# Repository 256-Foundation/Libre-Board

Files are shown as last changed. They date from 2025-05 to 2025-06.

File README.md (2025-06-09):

# Libre-Board
Open Source Bitcoin Mining Control Board.
Learn more at https://libreboard.org/

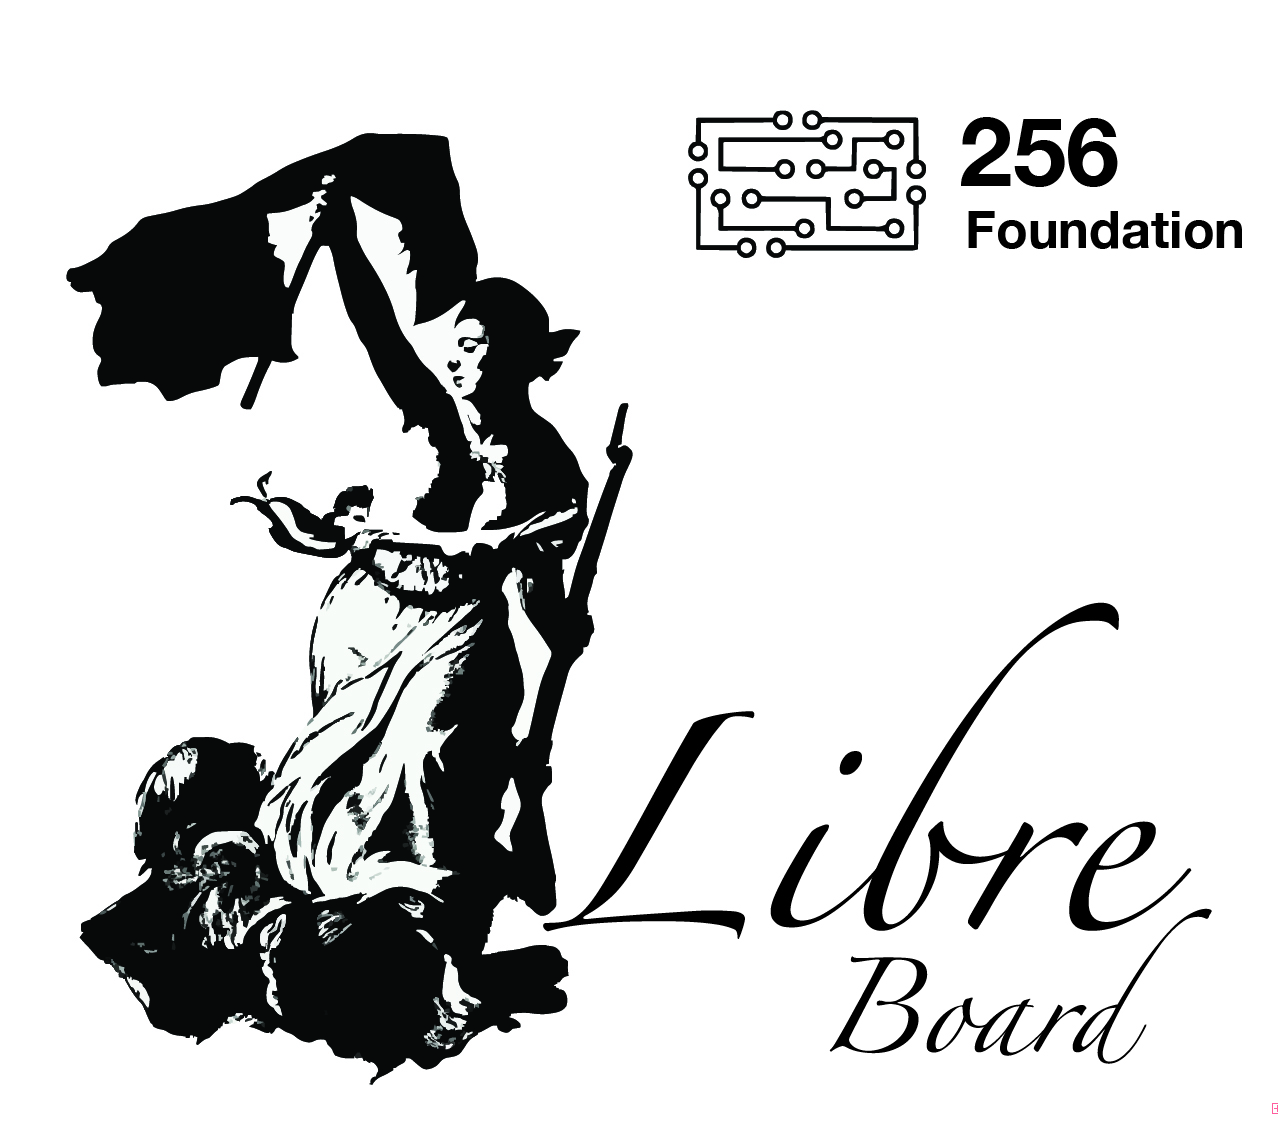
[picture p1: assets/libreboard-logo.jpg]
Libre Logo


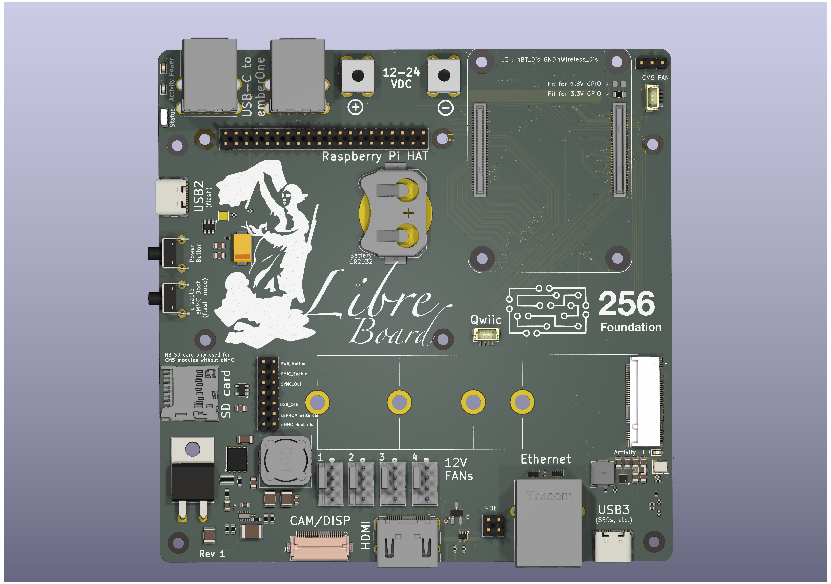
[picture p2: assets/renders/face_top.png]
Libre Board Top Face View


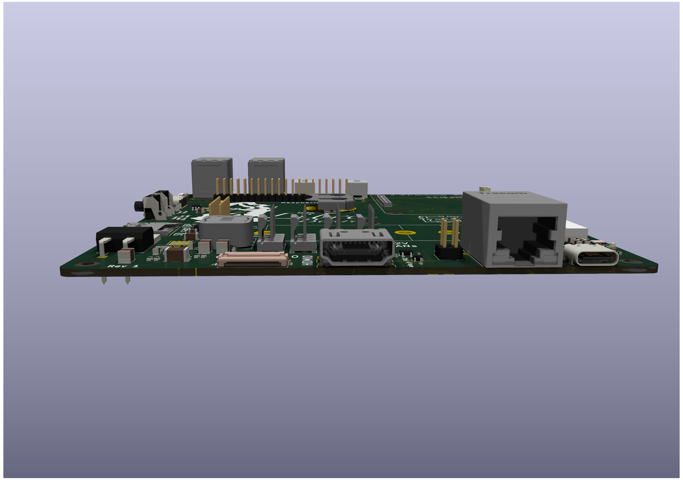
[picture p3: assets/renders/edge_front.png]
Libre Board Front Edge View


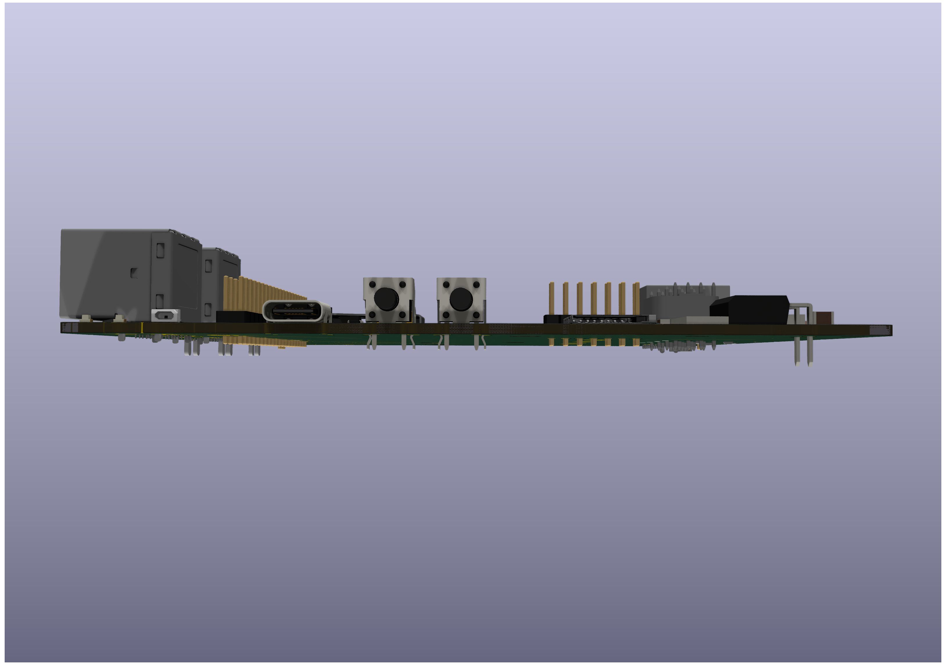
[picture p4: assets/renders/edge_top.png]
Libre Board Top Edge View


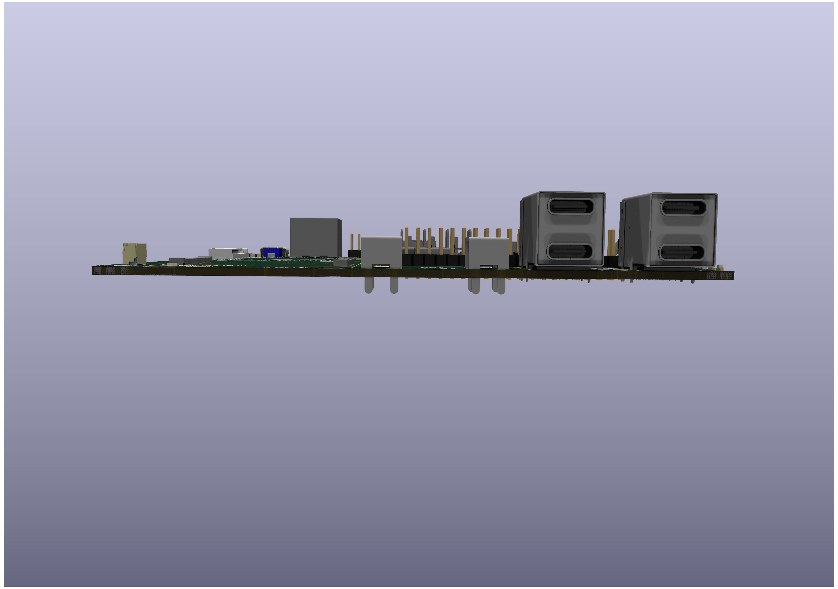
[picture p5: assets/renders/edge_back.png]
Libre Board Back Edge View


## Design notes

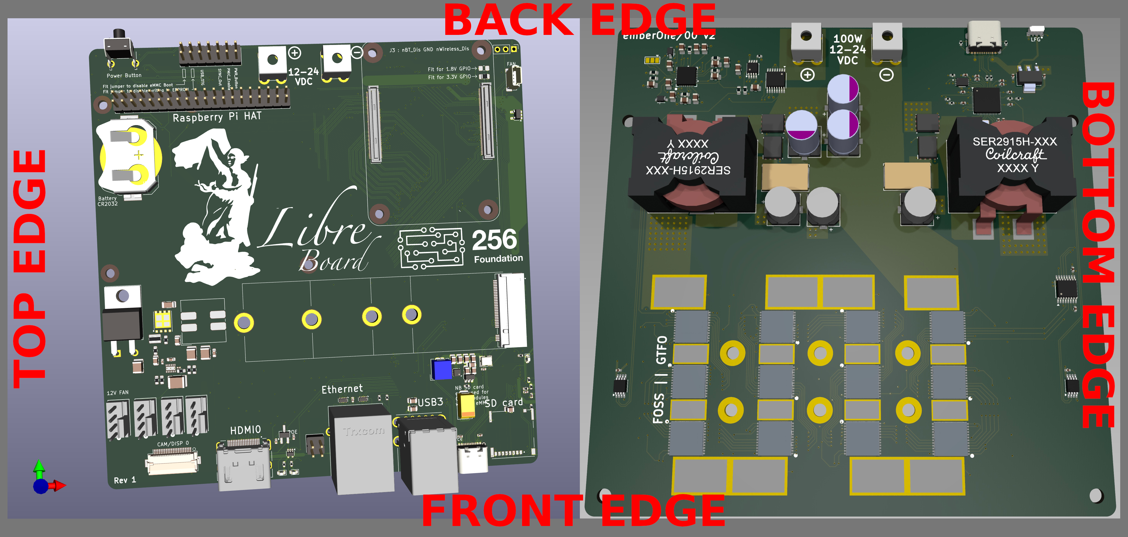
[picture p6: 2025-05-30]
assets/libreX.png

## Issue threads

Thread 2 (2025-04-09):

Change USB-A Ports to USB-C

Schnitzel, 2025-04-09:
currently Raspberry Pi Compute Module 5 IO board has two USB3.0 Ports of type A. as the EmberOne has USB-C we also want USB-C connectors

Closed 2025-06-09.

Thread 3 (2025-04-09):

Fan Connectors

Schnitzel, 2025-04-09:
Raspberry Pi Compute Module 5 IO board has a single JST-SH PWM fan connector - which we want to keep to cool any RaspberryPi
We need 4 fan connectors of the same type as regular fans but only 1 PWM signal for them

Closed 2025-09-24.

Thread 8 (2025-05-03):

Feature request: provision for graceful shutdown on power loss

rkuester, 2025-05-03:
Mujina OS would like the ability to gracefully shut down in the event of a power loss to shut down applications, write logs, avoid filesystem corruption, etc., but it needs a little help from the hardware. Perhaps supercaps or a small battery keeping the CM5 powered in the event of a power loss, and signaling for Linux to determine that the power has been lost. Having at least ten seconds of reserve would be ideal, but we might be able to make due with less.

Schnitzel, 2025-05-05:
Ah great idea! Let me look what we could leverage from existing solutions, maybe there is a Raspberry PI HAT that already provides such a solution?

zbomz, 2025-05-05:
I love this idea, but I would caution to not take it lightly thinking it's and easy implementation. We had to implement a small backup battery on the Owlet base station to ensure we could alert the user of a power loss in order to meet FDA requirements. The most challenging part of implementing something like this is designing for the worst case scenario of having multiple asynchronous, bursty loads (wifi, hdmi, ethernet, compute, etc.) fire at the same time when operating from the battery before the loads can be disabled. Judging by the 3D renderings I've seen on X, it looks like a CR2032 primary coin cell is being used to supply the backup power (sorry for the ensuing rant if I'm wrong on this).

While the capacity of the cell might be high enough to last for the requested 10 seconds, its internal impedance will be an issue. Primary coin cells have relatively high internal impedance that will cause the battery voltage to droop prohibitively low during short load bursts and result in a brown out. For example, the typical max "pulse current" for a lithium manganese CR2032 cell is 15mA. The idle power consumption of the CM5 is typically 400mA. The operating power consumption is typically 900mA. Add the possibility of Wifi transmitting when power is lost, and you're looking at over 1 amp of current draw. No single coin cell is going to be able to support that. You need something with low internal impedance. A small lithium polymer rechargeable battery with an accompanying charge controller IC is your best low-cost option for meeting the pulse current requirements, but it may not be suitable due to its sensitivity to temperatures above 70C.

zbomz, 2025-05-05:
Got it. Sorry for the rant about the coin cell! lol

Out of curiosity, I started musing about what it would take to supply 1A at 5V for 10 seconds. I'm trying to think of the lowest cost way to do it. What kind of budget are you hoping to implement this for?

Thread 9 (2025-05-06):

Feature request: S9 board plug and play

TimothyShimmin, 2025-05-06:
Hey I just heard about this [project](https://x.com/Schnitzel/status/1919446976577540429), that one of the goals is modularity.

Is there any intention of supporting boards straight out of corpo miners? I don't know what the limitations would be for that but it'd be nice to rip one out of an otherwise busted miner and slot it into this board.

econoalchemist, 2025-05-28:
There's a few different approaches: One would be to flash [Mujina](https://mujina.org/) onto an existing S9 board, though this probably won't be viable until sometime after the first release. Two would be to use Libre Board as the controller running Mujina and then connect it to the S9 hashboards with the [Adit Board](https://github.com/skot/aditBoard) adapter. A third option would be to fork Libre Board and modify it to be a direct replacement.

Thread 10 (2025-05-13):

Feature request: at least 4 USB-C ports directly on Libre Board

rkuester, 2025-05-13:
The Libre Board should have at least four USB-C ports in addition to the power and diagnostic port currently adjacent to the SD card slot.

The design currently has only two, but I think that's insufficient. Two ports allows for only one hash board plus one accessory (USB drive, keyboard, etc.); however, one of our modular system's selling points is that you can connect multiple hash boards via USB. One of the firmware's selling points is that it can talk to a variable number and types of hash boards, connected via USB. Thus I believe the out-of-the-box hardware should be able to show off these features without resort to an external hub.

Having four ports allows for three hash boards plus one accessory. Additionally, the design of ICs and connectors is such that four ports is like as easy to design-in as three ports.

If board space is an issue, I'd consider shifting the MIPI, HDMI, and Ethernet connectors over and eliminating the space between the Ethernet and HDMI connector.

Schnitzel, 2025-06-09:
this has been implemented in the newest version - see 2 USB3 stacks on the top:

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

this is not routed yet, also there is no USB controller yet, leaving this open until we have that.

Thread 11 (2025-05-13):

Feature request: board holes which align with those on emberOne

rkuester, 2025-05-13:
If Libre Board had holes in the corners which lined up with the holes on emberOne's corners, they could be stacked together nicely with standoffs.

Schnitzel, 2025-05-30:
yep, that's already part of the plan

Schnitzel, 2025-06-09:
this has been implemented in the newest version:

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

Schnitzel, 2025-06-09:
actually I just realized that the holes should probably align to the top of the image and not to the bottom as they do right now, need to move quite some stuff around for this

Closed 2025-06-09.

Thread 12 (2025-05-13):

Feature request: route serial console pins to thru-holes for .100 header

rkuester, 2025-05-13:
Pins 6, 8, and 10 on the Raspberry Pi 40-pin header are often used for a Linux serial console—The Way to get a command shell without needing monitors, keyboards, a configured network, etc., and often used for development and debugging when nothing else is working. It would ideal to preserve semi-easy access to the serial console even when a hat is in use on the 40-pin header.

Could we please route those signals to thru-holes for a 3-pin, .100"-centers header, even if we don't populate it with a header or connector? Ideally it'd be on a board edge so that a right-angle connector is an option.

As a helpful byproduct, the obvious use of those signals on the PCB might deter hat developers from using those pins for other purposes. We might mention that in our documentation.

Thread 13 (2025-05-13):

Feature request: an indicator LED identical to that of the emberOne

rkuester, 2025-05-13:
The emberOne has an RGB LED module we'll use in software for indicating presence, faults, etc. It's on the same board edge as the power rails. It would be nice if Libre Board had the same indicator, and if it were visible in parallel if the boards were all connected via a power rails.

rkuester, 2025-06-05:
I'd use the same [SK6812](https://www.adafruit.com/product/4691) @skot is using on the emberOne. It'll be slick if the hash boards and Libre board match.

The SK6812 uses an unlocked, one-pin data interface. It definitely requires connection to a SPI-capable data line on a Linux-based machine, to meet the timing requirements. Bit-banging from bare metal or a RTOS on a microcontroller might work to meet the SK6812's timing requirements, but Linux can't counted on to bit-bang that precisely.

It'll leave it to you to decide which SPI-capable pin this should be. Taking a quick glance at the CM5, it seems there are possibilities both on the HAT-compatible 40-pin header and exclusively on the 100-pin connectors. Putting it on the 40-pin's signals probably makes it more compatible with alternate compute modules. The LED does not need the SPI clock nor MISO. To not consume that SPI bus completely, I'd gate the signal to the LED with a chip select (driven low when off).

I considered the similar but easier-to-bit-bang [SK9822](https://learn.adafruit.com/adafruit-dotstar-leds/overview), which has a clock and data signal, but I didn't see any right-angle versions of those.

rkuester, 2025-06-05:
For completeness, I'll mention that we could likely implement something fancy using the PIO on the RPi CM5 to delegate timing requirements to hardware without using SPI per se. However, this approach is quite specific to the CM5 and might cut off our compatibility with other compute modules.

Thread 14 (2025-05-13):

Feature request: an 4-pin connector compatible with the Adafruit STEMMA and Sparkfun Qwicc standard

rkuester, 2025-05-13:
It might be a nice touch if we put a 4-pin JST SH connector on the board for the expansion I2C bus, compatible with the [Adafruit STEMMA](https://learn.adafruit.com/introducing-adafruit-stemma-qt/technical-specs) and [Sparkfun Qwicc](https://www.sparkfun.com/qwiic) standard. This would open plug-and-play access to the many sensor, actuator, indicator, etc. modules hobbyists use via those standards.

I realize this could be done with a hat; however, we could do this with just a connector, or the footprint for a connector, and instantly have a lot of fun out-of-the-box.

Closed 2025-06-09.

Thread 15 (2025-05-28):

Feature request: a momentary pushbutton for eMMC boot mode selection

rkuester, 2025-05-28:
I propose adding a momentary pushbutton in parallel with the existing boot jumper header that temporarily grounds the boot select pin when pressed during power-on. This would remove the hassle of finding and positioning jumpers, significantly improving the Mujina Firmware flashing process for developers and end users.

Currently, enabling USB bootloader mode on the CM5 daughterboard requires manually placing a jumper across the boot header pins, which is cumbersome during frequent development cycles. Since all CM5-compatible compute modules with eMMC don't boot from SD card, using the boot select jumper to enter USB loader mode is critical for programming these modules with rpiboot. I've tested this behavior using a jumper as a momentary connection and confirmed the CM5 only needs the boot pin pulled low for a few seconds after power is applied—once the boot sequence completes, the CM5 enters loader mode and waits for programming via USB.

Schnitzel, 2025-06-09:
this has been implemented in the newest version - see the secondary button on the left/top edge

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

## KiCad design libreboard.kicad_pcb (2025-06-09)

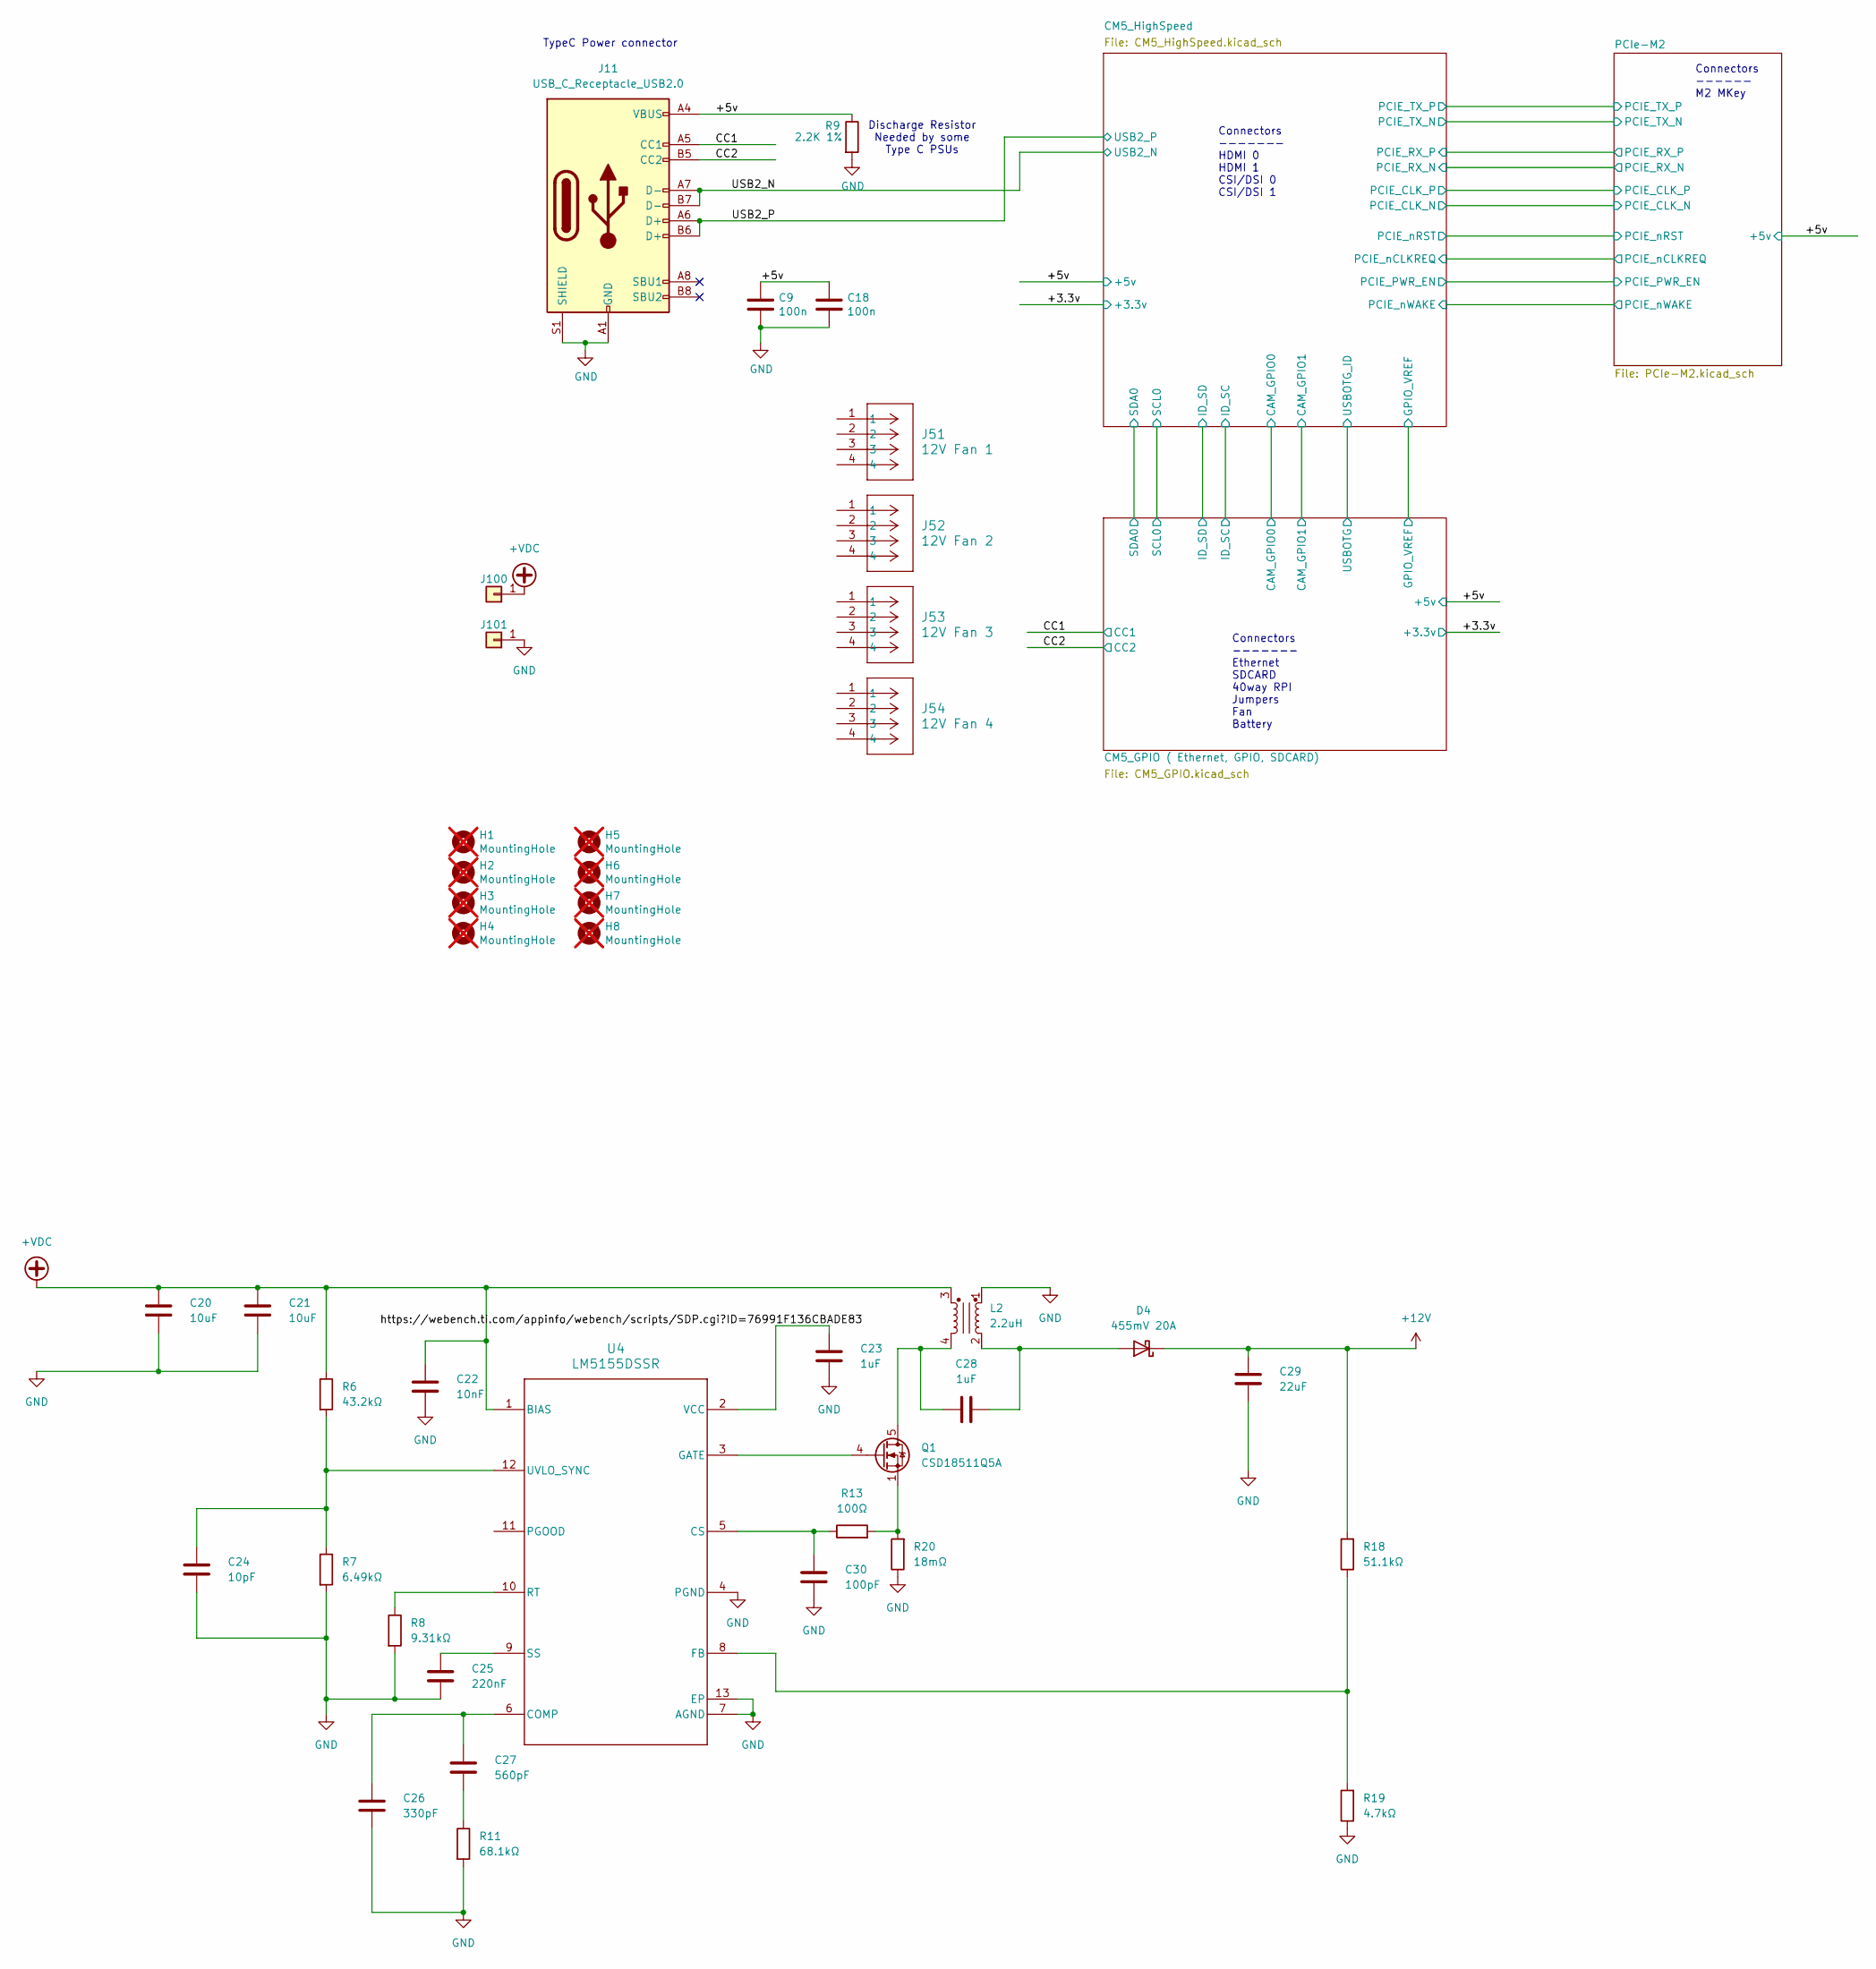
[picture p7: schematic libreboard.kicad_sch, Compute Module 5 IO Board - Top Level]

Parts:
C9, C18: 100n; C_0402_1005Metric; Part Description 0.1uF 10% 16V Ceramic Capacitor X7R 040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
C20, C21: 10uF; C_1210_3225Metric
C22: 10nF; C_0603_1608Metric
C23: 1uF; C_0603_1608Metric
C24: 10pF; C_0201_0603Metric
C25: 220nF; C_1812_4532Metric
C26: 330pF; C_0402_1005Metric
C27: 560pF; C_0805_2012Metric
C28: 1uF; C_1206_3216Metric
C29: 22uF; C_1210_3225Metric
C30: 100pF; C_0805_2012Metric
D4: 455mV 20A; TO-220-2_Horizontal_TabDown
H1, H2, H3, H4, H5, H6, H7, H8: MountingHole; MountingHole_2.7mm_M2.5_DIN965; Part Description M2.5 mounting hole; not fitted
J11: USB_C_Receptacle_USB2.0; USB_C_Receptacle_GCT_USB4105-xx-A_16P_TopMnt_Horizontal; Part Description USBC USB2 data and power connector
J51: 12V Fan 1; CONN_SD-47053-001_H10p00_MOL
J52: 12V Fan 2; CONN_SD-47053-001_H10p00_MOL
J53: 12V Fan 3; CONN_SD-47053-001_H10p00_MOL
J54: 12V Fan 4; CONN_SD-47053-001_H10p00_MOL
J100, J101: Screw Terminal; 7770-screw-terminal; PARTNO 36-7770
L2: 2.2uH; L_Bourns_SRF1260
Q1: CSD18511Q5A; VSONP-8-1EP_5x6_P1.27mm; PARTNO CSD18511Q5A
R6: 43.2kΩ; R_0603_1608Metric
R7: 6.49kΩ; R_0603_1608Metric
R8: 9.31kΩ; R_0603_1608Metric
R9: 2.2K 1%; R_0402_1005Metric; Part Description Resistor 2.2K M1005 1% 63mW
R11: 68.1kΩ; R_0603_1608Metric
R13: 100Ω; R_0603_1608Metric
R18: 51.1kΩ; R_0603_1608Metric
R19: 4.7kΩ; R_0603_1608Metric
R20: 18mΩ; R_0612_1632Metric
U4: LM5155DSSR; DSS0012B

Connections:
+12V: C29.2, D4.1 (K), R18.2
+VDC: C20.2, C21.2, C22.2, J100.1, L2.3, R6.1, U4.1 (BIAS)
/+5v: C9.1, C18.1, J11.A4 (VBUS), J11.A9 (VBUS), J11.B4 (VBUS), J11.B9 (VBUS), R9.1; also elsewhere on the board
/CC1: J11.A5 (CC1); also elsewhere on the board
/CC2: J11.B5 (CC2); also elsewhere on the board
/USB2_N: J11.A7 (D-), J11.B7 (D-); also elsewhere on the board
/USB2_P: J11.A6 (D+), J11.B6 (D+); also elsewhere on the board
GND: C9.2, C18.2, C20.1, C21.1, C22.1, C23.1, C24.1, C25.1, C26.1, C29.1, C30.1, J11.A1 (GND), J11.A12 (GND), J11.B1 (GND), J11.B12 (GND), J11.S1 (SHIELD), J101.1, L2.1, R7.2, R8.2, R9.2, R11.2, R19.1, R20.1, U4.4 (PGND), U4.7 (AGND), U4.13 (EP); also elsewhere on the board
unnamed: C27.1, R11.1
unnamed: C28.1, L2.4, Q1.5 (D), Q1.6 (D), Q1.7 (D), Q1.8 (D)
unnamed: C28.2, D4.2 (A), L2.2
unnamed: Q1.4 (G), U4.3 (GATE)
unnamed: Q1.1 (S), Q1.2 (S), Q1.3 (S), R13.2, R20.2
unnamed: C26.2, C27.2, U4.6 (COMP)
unnamed: C30.2, R13.1, U4.5 (CS)
unnamed: R18.1, R19.2, U4.8 (FB)
unnamed: R8.1, U4.10 (RT)
unnamed: C25.2, U4.9 (SS)
unnamed: C24.2, R6.2, R7.1, U4.12 (UVLO_SYNC)
unnamed: C23.2, U4.2 (VCC)

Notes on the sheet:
Connectors ------- Ethernet SDCARD 40way RPI Jumpers Fan Battery
Connectors ------ M2 MKey
Discharge Resistor Needed by some Type C PSUs
TypeC Power connector
Connectors ------- HDMI 0 HDMI 1 CSI/DSI 0 CSI/DSI 1

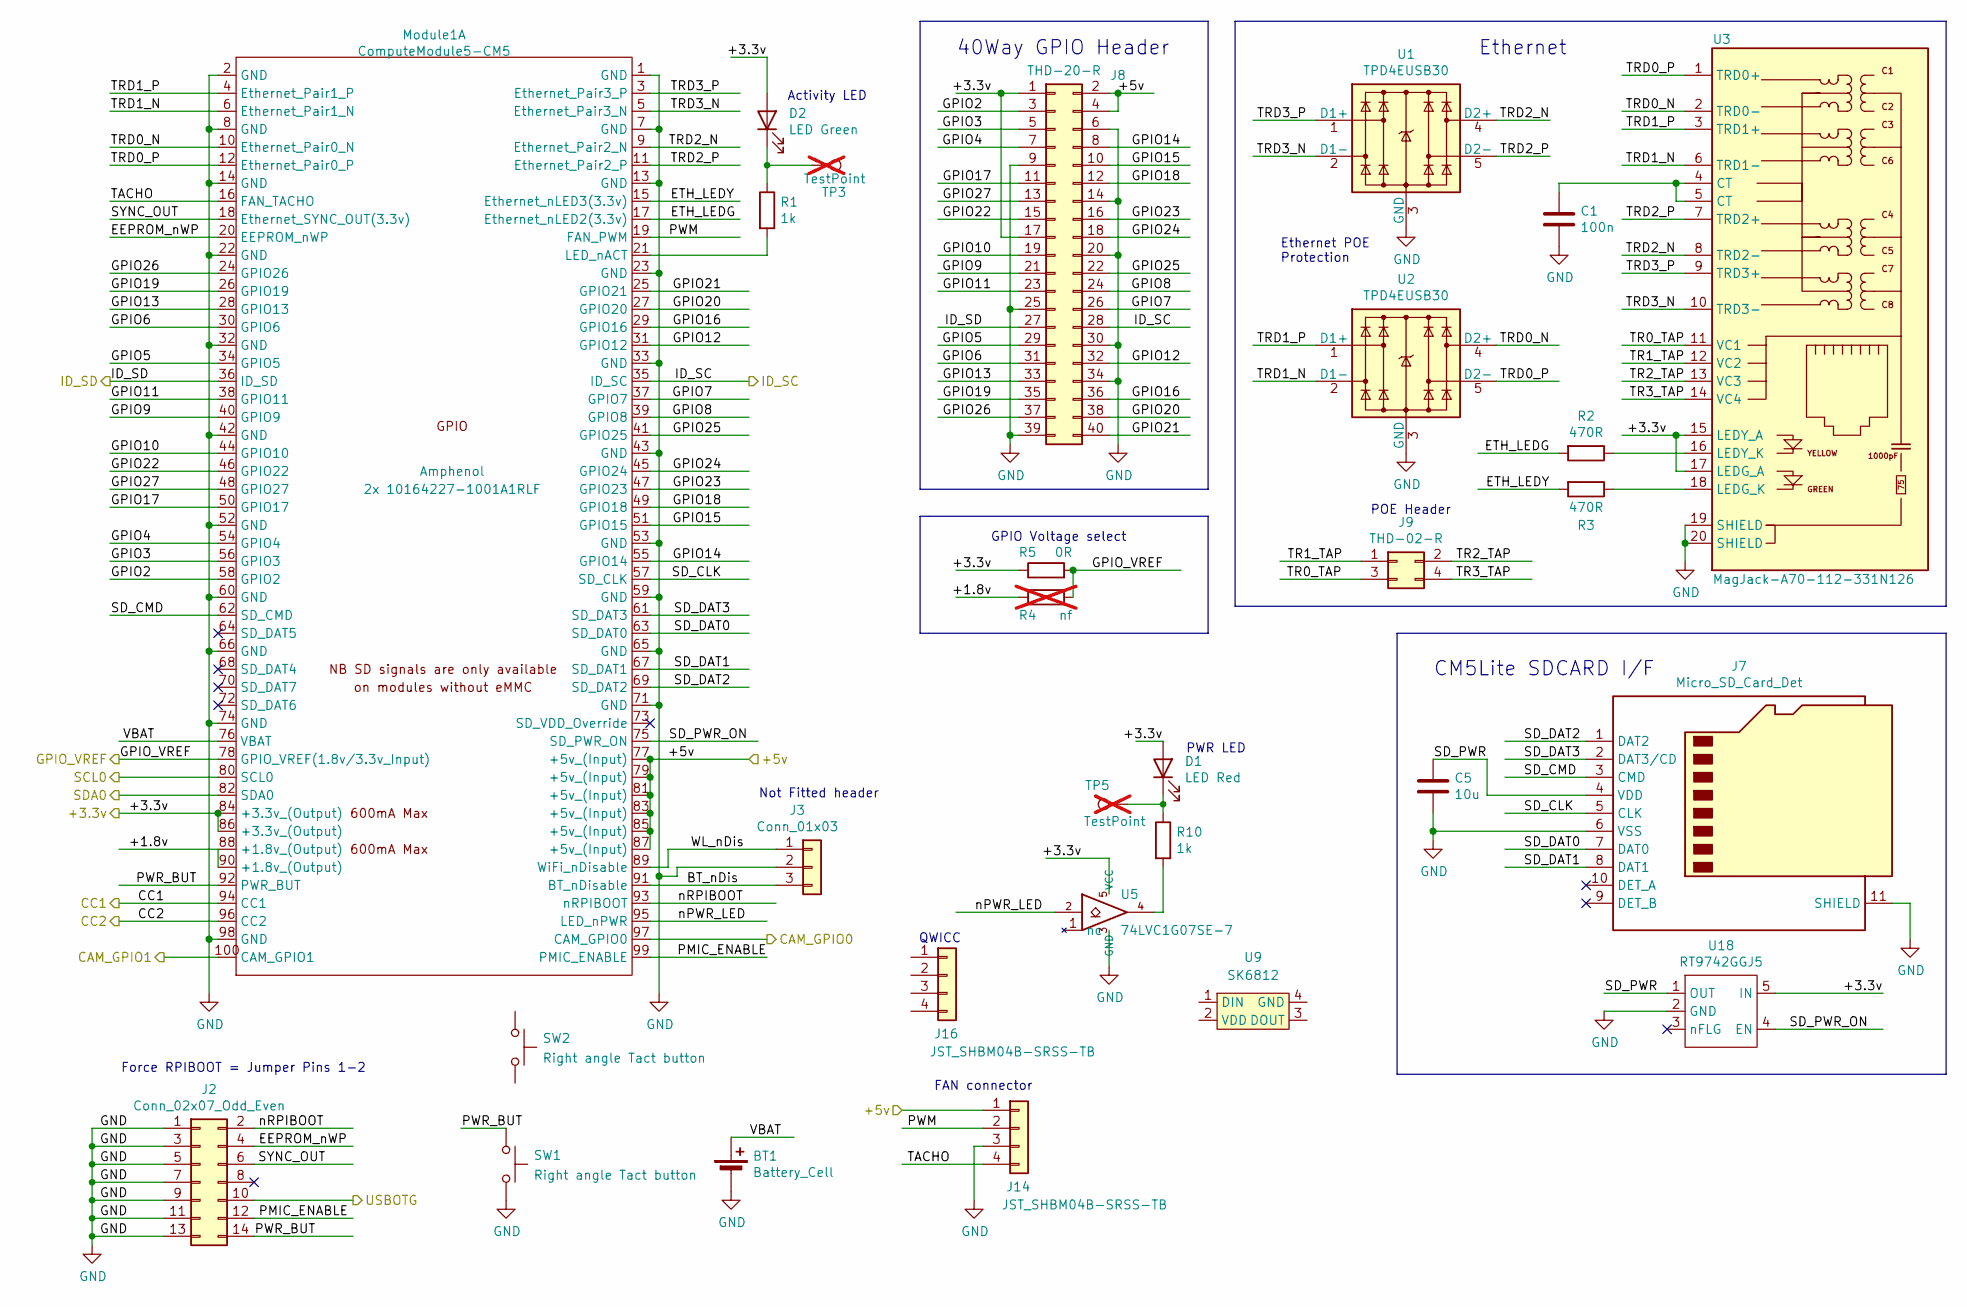
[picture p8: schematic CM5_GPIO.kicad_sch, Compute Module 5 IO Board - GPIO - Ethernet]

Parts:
BT1: Battery_Cell; BatteryHolder_Keystone_3034_1x20mm; Part Description Battery Retainer Coin, 20.0mm 1 Cell SM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
C1: 100n; C_0402_1005Metric; Part Description 0.1uF 10% 16V Ceramic Capacitor X7R 040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
C5: 10u; C_0805_2012Metric; Part Description 10uF 10% 10V Ceramic Capacitor X7R 0805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
D1: LED Red; LED_0603_1608Metric; Part Description Red 620nm LED Indication - Discrete 2.2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
D2: LED Green; LED_0603_1608Metric; Part Description Green 572nm LED Indication - Discrete 2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
J2: Conn_02x07_Odd_Even; PinHeader_2x07_P2.54mm_Vertical; Part Description PinHeader_2x07_P2.54mm_Vertical
J3: Conn_01x03; PinHeader_1x03_P2.54mm_Vertical; Part Description 3pin 0.1" connector
J7: Micro_SD_Card_Det; SDCARD_MOLEX_503398-1892; Part Description 9 (8 + 1) Position Card Connector micro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
J8: THD-20-R; PinHeader_2x20_P2.54mm_Vertical; Part Description PinHeader_2x20_P2.54mm_Vertical
J9: THD-02-R; PinHeader_2x02_P2.54mm_Vertical; Part Description PinHeader_2x02_P2.54mm_Vertical
J14, J16: JST_SHBM04B-SRSS-TB; JST_SH_BM04B-SRSS-TB_1x04-1MP_P1.00mm_Vertical; Part Description 4 pin vertical 1mm pitch connector
Module1: ComputeModule5-CM5; Raspberry-Pi-5-Compute-Module; Part Description 100 Position Connector Receptacle, Cent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
R1, R10: 1k; R_0402_1005Metric; Part Description Resistor 1K M1005 1% 63mW
R2, R3: 470R; R_0402_1005Metric; Part Description Resistor 470R M1005 1% 63mW
R4: nf; R_0805_2012Metric_Pad1.20x1.40mm_HandSolder; not fitted
R5: 0R; R_0805_2012Metric_Pad1.20x1.40mm_HandSolder; Part Description Resistor 0R M2012 5%
SW1, SW2: Right angle Tact button; SW_Tactile_SPST_Angled_PTS645Vx58-2LFS; Part Description Right angle through hole Tact switch
TP3, TP5: TestPoint; TestPoint_Pad_2.0x2.0mm; Part Description Test point; not fitted
U1, U2: TPD4EUSB30; USON-10_2.5x1.0mm_P0.5mm; Part Description Quad TVS diode for high speed signals (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
U3: MagJack-A70-112-331N126; TRJG0926HENL; Part Description Gigabit Ethernet Magjack
U5: 74LVC1G07SE-7; SOT-353_SC-70-5; Part Description Buffer, Non-Inverting 1 Element 1 Bit p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
U9: SK6812; LED-SMD_4P-L4.0-W1.6-L; LCSC C2890037
U18: RT9742GGJ5; SOT-23-5; Part Description Power Switch/Driver 1:1 N-Channel 1A TS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

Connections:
/+3.3v: D1.2 (A), D2.2 (A), J8.1, J8.17, Module1.84 (+3.3v_(Output)), Module1.86 (+3.3v_(Output)), R5.1, U3.15 (LEDY_A), U3.17 (LEDG_A), U5.5 (VCC), U18.5 (IN); also elsewhere on the board
/+5v: J8.2, J8.4, J14.1, Module1.77 (+5v_(Input)), Module1.79 (+5v_(Input)), Module1.81 (+5v_(Input)), Module1.83 (+5v_(Input)), Module1.85 (+5v_(Input)), Module1.87 (+5v_(Input)); also elsewhere on the board
/CC1: Module1.94 (CC1); also elsewhere on the board
/CC2: Module1.96 (CC2); also elsewhere on the board
/CM5_GPIO ( Ethernet, GPIO, SDCARD)/+1.8v: Module1.88 (+1.8v_(Output)), Module1.90 (+1.8v_(Output)), R4.1
/CM5_GPIO ( Ethernet, GPIO, SDCARD)/BT_nDis: J3.3, Module1.91 (BT_nDisable)
/CM5_GPIO ( Ethernet, GPIO, SDCARD)/CAM_GPIO0: Module1.97 (CAM_GPIO0); also elsewhere on the board
/CM5_GPIO ( Ethernet, GPIO, SDCARD)/CAM_GPIO1: Module1.100 (CAM_GPIO1); also elsewhere on the board
/CM5_GPIO ( Ethernet, GPIO, SDCARD)/EEPROM_nWP: J2.4, Module1.20 (EEPROM_nWP)
/CM5_GPIO ( Ethernet, GPIO, SDCARD)/ETH_LEDG: Module1.17 (Ethernet_nLED2(3.3v)), R2.2
/CM5_GPIO ( Ethernet, GPIO, SDCARD)/ETH_LEDY: Module1.15 (Ethernet_nLED3(3.3v)), R3.2
/CM5_GPIO ( Ethernet, GPIO, SDCARD)/GPIO2: J8.3, Module1.58 (GPIO2)
/CM5_GPIO ( Ethernet, GPIO, SDCARD)/GPIO3: J8.5, Module1.56 (GPIO3)
/CM5_GPIO ( Ethernet, GPIO, SDCARD)/GPIO4: J8.7, Module1.54 (GPIO4)
/CM5_GPIO ( Ethernet, GPIO, SDCARD)/GPIO5: J8.29, Module1.34 (GPIO5)
/CM5_GPIO ( Ethernet, GPIO, SDCARD)/GPIO6: J8.31, Module1.30 (GPIO6)
/CM5_GPIO ( Ethernet, GPIO, SDCARD)/GPIO7: J8.26, Module1.37 (GPIO7)
/CM5_GPIO ( Ethernet, GPIO, SDCARD)/GPIO8: J8.24, Module1.39 (GPIO8)
/CM5_GPIO ( Ethernet, GPIO, SDCARD)/GPIO9: J8.21, Module1.40 (GPIO9)
/CM5_GPIO ( Ethernet, GPIO, SDCARD)/GPIO10: J8.19, Module1.44 (GPIO10)
/CM5_GPIO ( Ethernet, GPIO, SDCARD)/GPIO11: J8.23, Module1.38 (GPIO11)
/CM5_GPIO ( Ethernet, GPIO, SDCARD)/GPIO12: J8.32, Module1.31 (GPIO12)
/CM5_GPIO ( Ethernet, GPIO, SDCARD)/GPIO13: J8.33, Module1.28 (GPIO13)
/CM5_GPIO ( Ethernet, GPIO, SDCARD)/GPIO14: J8.8, Module1.55 (GPIO14)
/CM5_GPIO ( Ethernet, GPIO, SDCARD)/GPIO15: J8.10, Module1.51 (GPIO15)
/CM5_GPIO ( Ethernet, GPIO, SDCARD)/GPIO16: J8.36, Module1.29 (GPIO16)
/CM5_GPIO ( Ethernet, GPIO, SDCARD)/GPIO17: J8.11, Module1.50 (GPIO17)
/CM5_GPIO ( Ethernet, GPIO, SDCARD)/GPIO18: J8.12, Module1.49 (GPIO18)
/CM5_GPIO ( Ethernet, GPIO, SDCARD)/GPIO19: J8.35, Module1.26 (GPIO19)
/CM5_GPIO ( Ethernet, GPIO, SDCARD)/GPIO20: J8.38, Module1.27 (GPIO20)
/CM5_GPIO ( Ethernet, GPIO, SDCARD)/GPIO21: J8.40, Module1.25 (GPIO21)
/CM5_GPIO ( Ethernet, GPIO, SDCARD)/GPIO22: J8.15, Module1.46 (GPIO22)
/CM5_GPIO ( Ethernet, GPIO, SDCARD)/GPIO23: J8.16, Module1.47 (GPIO23)
/CM5_GPIO ( Ethernet, GPIO, SDCARD)/GPIO24: J8.18, Module1.45 (GPIO24)
/CM5_GPIO ( Ethernet, GPIO, SDCARD)/GPIO25: J8.22, Module1.41 (GPIO25)
/CM5_GPIO ( Ethernet, GPIO, SDCARD)/GPIO26: J8.37, Module1.24 (GPIO26)
/CM5_GPIO ( Ethernet, GPIO, SDCARD)/GPIO27: J8.13, Module1.48 (GPIO27)
/CM5_GPIO ( Ethernet, GPIO, SDCARD)/GPIO_VREF: Module1.78 (GPIO_VREF(1.8v/3.3v_Input)), R4.2, R5.2
/CM5_GPIO ( Ethernet, GPIO, SDCARD)/ID_SC: J8.28, Module1.35 (ID_SC)
/CM5_GPIO ( Ethernet, GPIO, SDCARD)/ID_SD: J8.27, Module1.36 (ID_SD)
/CM5_GPIO ( Ethernet, GPIO, SDCARD)/PMIC_ENABLE: J2.12, Module1.99 (PMIC_ENABLE)
/CM5_GPIO ( Ethernet, GPIO, SDCARD)/PWM: J14.2, Module1.19 (FAN_PWM)
/CM5_GPIO ( Ethernet, GPIO, SDCARD)/PWR_BUT: J2.14, Module1.92 (PWR_BUT), SW1.1
/CM5_GPIO ( Ethernet, GPIO, SDCARD)/SD_CLK: J7.5 (CLK), Module1.57 (SD_CLK)
/CM5_GPIO ( Ethernet, GPIO, SDCARD)/SD_CMD: J7.3 (CMD), Module1.62 (SD_CMD)
/CM5_GPIO ( Ethernet, GPIO, SDCARD)/SD_DAT0: J7.7 (DAT0), Module1.63 (SD_DAT0)
/CM5_GPIO ( Ethernet, GPIO, SDCARD)/SD_DAT1: J7.8 (DAT1), Module1.67 (SD_DAT1)
/CM5_GPIO ( Ethernet, GPIO, SDCARD)/SD_DAT2: J7.1 (DAT2), Module1.69 (SD_DAT2)
/CM5_GPIO ( Ethernet, GPIO, SDCARD)/SD_DAT3: J7.2 (DAT3/CD), Module1.61 (SD_DAT3)
/CM5_GPIO ( Ethernet, GPIO, SDCARD)/SD_PWR: C5.1, J7.4 (VDD), U18.1 (OUT)
/CM5_GPIO ( Ethernet, GPIO, SDCARD)/SD_PWR_ON: Module1.75 (SD_PWR_ON), U18.4 (EN)
/CM5_GPIO ( Ethernet, GPIO, SDCARD)/SYNC_OUT: J2.6, Module1.18 (Ethernet_SYNC_OUT(3.3v))
/CM5_GPIO ( Ethernet, GPIO, SDCARD)/TACHO: J14.4, Module1.16 (FAN_TACHO)
/CM5_GPIO ( Ethernet, GPIO, SDCARD)/TR0_TAP: J9.3, U3.11 (VC1)
/CM5_GPIO ( Ethernet, GPIO, SDCARD)/TR1_TAP: J9.1, U3.12 (VC2)
/CM5_GPIO ( Ethernet, GPIO, SDCARD)/TR2_TAP: J9.2, U3.13 (VC3)
/CM5_GPIO ( Ethernet, GPIO, SDCARD)/TR3_TAP: J9.4, U3.14 (VC4)
/CM5_GPIO ( Ethernet, GPIO, SDCARD)/TRD0_N: Module1.10 (Ethernet_Pair0_N), U2.4 (D2+), U2.7, U3.2 (TRD0-)
/CM5_GPIO ( Ethernet, GPIO, SDCARD)/TRD0_P: Module1.12 (Ethernet_Pair0_P), U2.5 (D2-), U2.6, U3.1 (TRD0+)
/CM5_GPIO ( Ethernet, GPIO, SDCARD)/TRD1_N: Module1.6 (Ethernet_Pair1_N), U2.2 (D1-), U2.9, U3.6 (TRD1-)
/CM5_GPIO ( Ethernet, GPIO, SDCARD)/TRD1_P: Module1.4 (Ethernet_Pair1_P), U2.1 (D1+), U2.10, U3.3 (TRD1+)
/CM5_GPIO ( Ethernet, GPIO, SDCARD)/TRD2_N: Module1.9 (Ethernet_Pair2_N), U1.4 (D2+), U1.7, U3.8 (TRD2-)
/CM5_GPIO ( Ethernet, GPIO, SDCARD)/TRD2_P: Module1.11 (Ethernet_Pair2_P), U1.5 (D2-), U1.6, U3.7 (TRD2+)
/CM5_GPIO ( Ethernet, GPIO, SDCARD)/TRD3_N: Module1.5 (Ethernet_Pair3_N), U1.2 (D1-), U1.9, U3.10 (TRD3-)
/CM5_GPIO ( Ethernet, GPIO, SDCARD)/TRD3_P: Module1.3 (Ethernet_Pair3_P), U1.1 (D1+), U1.10, U3.9 (TRD3+)
/CM5_GPIO ( Ethernet, GPIO, SDCARD)/USBOTG: J2.10; also elsewhere on the board
/CM5_GPIO ( Ethernet, GPIO, SDCARD)/VBAT: BT1.1 (+), Module1.76 (VBAT)
/CM5_GPIO ( Ethernet, GPIO, SDCARD)/WL_nDis: J3.1, Module1.89 (WiFi_nDisable)
/CM5_GPIO ( Ethernet, GPIO, SDCARD)/nPWR_LED: Module1.95 (LED_nPWR), U5.2
/CM5_GPIO ( Ethernet, GPIO, SDCARD)/nRPIBOOT: J2.2, Module1.93 (nRPIBOOT)
/CM5_HighSpeed/SCL0: Module1.80 (SCL0); also elsewhere on the board
/CM5_HighSpeed/SDA0: Module1.82 (SDA0); also elsewhere on the board
GND: BT1.2 (-), C1.2, C5.2, J2.1, J2.3, J2.5, J2.7, J2.9, J2.11, J2.13, J3.2, J7.6 (VSS), J7.11 (SHIELD), J8.6, J8.9, J8.14, J8.20, J8.25, J8.30, J8.34, J8.39, J14.3, Module1.1 (GND), Module1.2 (GND), Module1.7 (GND), Module1.8 (GND), Module1.13 (GND), Module1.14 (GND), Module1.22 (GND), Module1.23 (GND), Module1.32 (GND), Module1.33 (GND), Module1.42 (GND), Module1.43 (GND), Module1.52 (GND), Module1.53 (GND), Module1.59 (GND), Module1.60 (GND), Module1.65 (GND), Module1.66 (GND), Module1.71 (GND), Module1.74 (GND), Module1.98 (GND), SW1.2, U1.3 (GND), U1.8 (GND), U2.3 (GND), U2.8 (GND), U3.19 (SHIELD), U3.20 (SHIELD), U5.3 (GND), U18.2 (GND); also elsewhere on the board
unnamed: C1.1, U3.4 (CT), U3.5 (CT)
unnamed: D1.1 (K), R10.1, TP5.1
unnamed: D2.1 (K), R1.1, TP3.1
unnamed: Module1.21 (LED_nACT), R1.2
unnamed: R10.2, U5.4
unnamed: R3.1, U3.18 (LEDG_K)
unnamed: R2.1, U3.16 (LEDY_K)

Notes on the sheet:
QWICC
40Way GPIO Header
Activity LED
FAN connector
Ethernet POE Protection
GPIO Voltage select
Not Fitted header
POE Header
Force RPIBOOT = Jumper Pins 1-2
PWR LED
Ethernet
CM5Lite SDCARD I/F

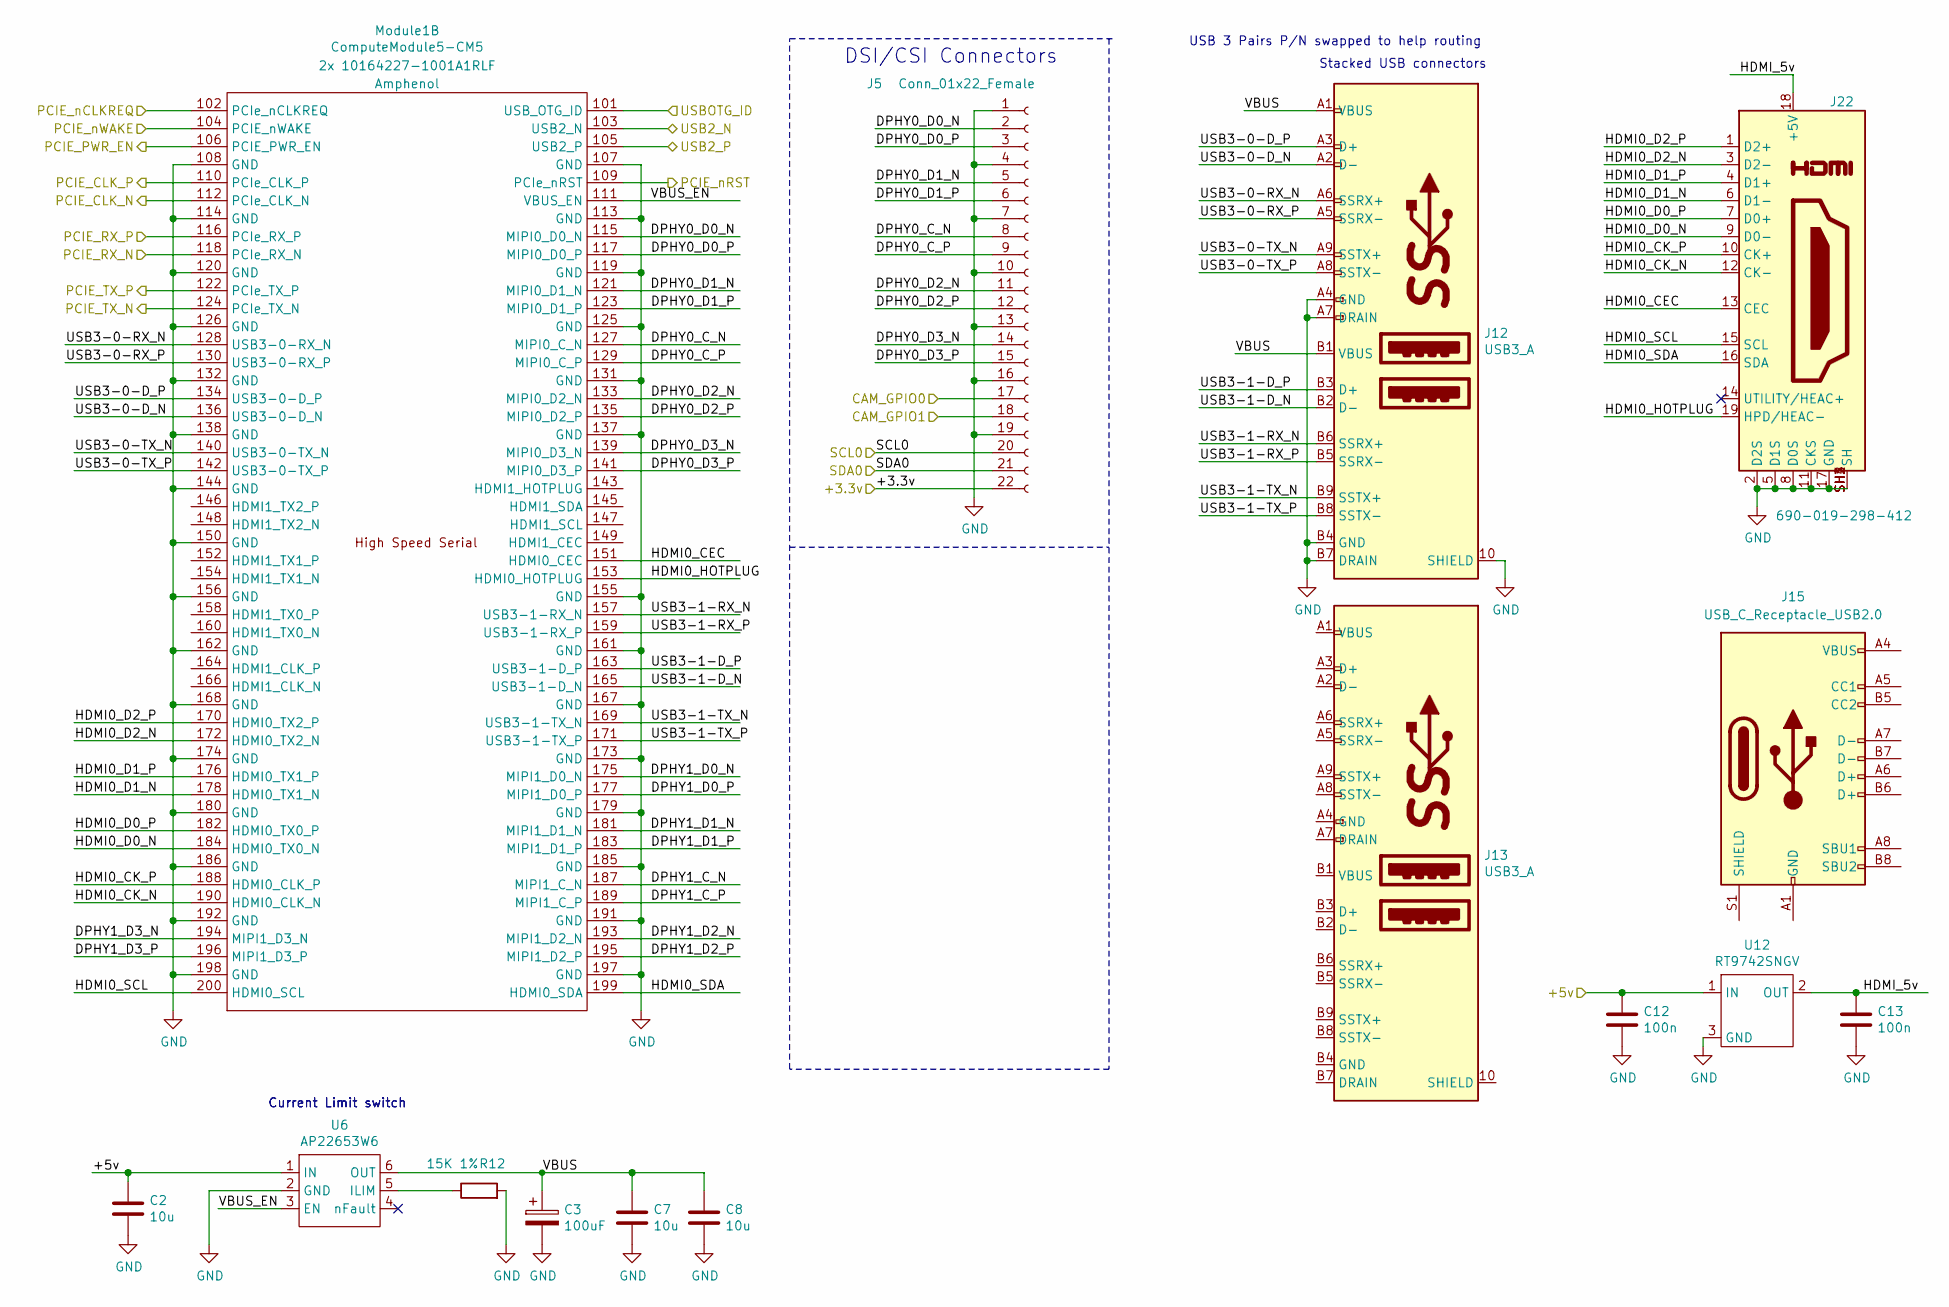
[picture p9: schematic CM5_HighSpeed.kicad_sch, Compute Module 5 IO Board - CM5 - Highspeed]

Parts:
C2, C7, C8: 10u; C_0805_2012Metric; Part Description 10uF 10% 10V Ceramic Capacitor X7R 0805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
C3: 100uF; CP_EIA-7343-31_Kemet-D; Part Description Capacitor, SP-Cap, 100u, 6.3V, 15mR ESR
C12, C13: 100n; C_0402_1005Metric; Part Description 0.1uF 10% 16V Ceramic Capacitor X7R 040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
J5: Conn_01x22_Female; Hirose_FH12-22S-0.5SH_1x22-1MP_P0.50mm_Horizontal; Part Description 22 Position FFC, FPC Connector Contacts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
J12, J13: USB3_A; MTCONN_UBAF30-D2011; Part Description Dual USB 3 connector
J15: USB_C_Receptacle_USB2.0; USB_C_Receptacle_GCT_USB4105-xx-A_16P_TopMnt_Horizontal; Part Description USBC USB2 data and power connector
J22: 690-019-298-412; EDAC 690-019-298-412; Part Description HDMI Connector, Right Angle, 19 Contact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
Module1: ComputeModule5-CM5; Raspberry-Pi-5-Compute-Module; Part Description 100 Position Connector Receptacle, Cent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
R12: 15K 1%; R_0402_1005Metric; Part Description Resistor 15K M1005 1% 63mW
U6: AP22653W6; SOT-23-6; Part Description Power Switch/Driver 1:1 P-Channel 2.1A 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
U12: RT9742SNGV; TSOT-23_HandSoldering; Part Description Power Switch/Driver 1:1 N-Channel 500mA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

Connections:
/+3.3v: J5.22; also elsewhere on the board
/+5v: C2.1, C12.1, U6.1 (IN), U12.1 (IN); also elsewhere on the board
/CM5_GPIO ( Ethernet, GPIO, SDCARD)/CAM_GPIO0: J5.17; also elsewhere on the board
/CM5_GPIO ( Ethernet, GPIO, SDCARD)/CAM_GPIO1: J5.18; also elsewhere on the board
/CM5_GPIO ( Ethernet, GPIO, SDCARD)/USBOTG: Module1.101 (USB_OTG_ID); also elsewhere on the board
/CM5_HighSpeed/DPHY0_C_N: J5.8, Module1.127 (MIPI0_C_N)
/CM5_HighSpeed/DPHY0_C_P: J5.9, Module1.129 (MIPI0_C_P)
/CM5_HighSpeed/DPHY0_D0_N: J5.2, Module1.115 (MIPI0_D0_N)
/CM5_HighSpeed/DPHY0_D0_P: J5.3, Module1.117 (MIPI0_D0_P)
/CM5_HighSpeed/DPHY0_D1_N: J5.5, Module1.121 (MIPI0_D1_N)
/CM5_HighSpeed/DPHY0_D1_P: J5.6, Module1.123 (MIPI0_D1_P)
/CM5_HighSpeed/DPHY0_D2_N: J5.11, Module1.133 (MIPI0_D2_N)
/CM5_HighSpeed/DPHY0_D2_P: J5.12, Module1.135 (MIPI0_D2_P)
/CM5_HighSpeed/DPHY0_D3_N: J5.14, Module1.139 (MIPI0_D3_N)
/CM5_HighSpeed/DPHY0_D3_P: J5.15, Module1.141 (MIPI0_D3_P)
/CM5_HighSpeed/DPHY1_C_N: Module1.187 (MIPI1_C_N)
/CM5_HighSpeed/DPHY1_C_P: Module1.189 (MIPI1_C_P)
/CM5_HighSpeed/DPHY1_D0_N: Module1.175 (MIPI1_D0_N)
/CM5_HighSpeed/DPHY1_D0_P: Module1.177 (MIPI1_D0_P)
/CM5_HighSpeed/DPHY1_D1_N: Module1.181 (MIPI1_D1_N)
/CM5_HighSpeed/DPHY1_D1_P: Module1.183 (MIPI1_D1_P)
/CM5_HighSpeed/DPHY1_D2_N: Module1.193 (MIPI1_D2_N)
/CM5_HighSpeed/DPHY1_D2_P: Module1.195 (MIPI1_D2_P)
/CM5_HighSpeed/DPHY1_D3_N: Module1.194 (MIPI1_D3_N)
/CM5_HighSpeed/DPHY1_D3_P: Module1.196 (MIPI1_D3_P)
/CM5_HighSpeed/HDMI0_CEC: J22.13 (CEC), Module1.151 (HDMI0_CEC)
/CM5_HighSpeed/HDMI0_CK_N: J22.12 (CK-), Module1.190 (HDMI0_CLK_N)
/CM5_HighSpeed/HDMI0_CK_P: J22.10 (CK+), Module1.188 (HDMI0_CLK_P)
/CM5_HighSpeed/HDMI0_D0_N: J22.9 (D0-), Module1.184 (HDMI0_TX0_N)
/CM5_HighSpeed/HDMI0_D0_P: J22.7 (D0+), Module1.182 (HDMI0_TX0_P)
/CM5_HighSpeed/HDMI0_D1_N: J22.6 (D1-), Module1.178 (HDMI0_TX1_N)
/CM5_HighSpeed/HDMI0_D1_P: J22.4 (D1+), Module1.176 (HDMI0_TX1_P)
/CM5_HighSpeed/HDMI0_D2_N: J22.3 (D2-), Module1.172 (HDMI0_TX2_N)
/CM5_HighSpeed/HDMI0_D2_P: J22.1 (D2+), Module1.170 (HDMI0_TX2_P)
/CM5_HighSpeed/HDMI0_HOTPLUG: J22.19 (HPD/HEAC-), Module1.153 (HDMI0_HOTPLUG)
/CM5_HighSpeed/HDMI0_SCL: J22.15 (SCL), Module1.200 (HDMI0_SCL)
/CM5_HighSpeed/HDMI0_SDA: J22.16 (SDA), Module1.199 (HDMI0_SDA)
/CM5_HighSpeed/HDMI_5v: C13.1, J22.18 (+5V), U12.2 (OUT)
/CM5_HighSpeed/PCIE_CLK_N: Module1.112 (PCIe_CLK_N); also elsewhere on the board
/CM5_HighSpeed/PCIE_CLK_P: Module1.110 (PCIe_CLK_P); also elsewhere on the board
/CM5_HighSpeed/PCIE_PWR_EN: Module1.106 (PCIE_PWR_EN); also elsewhere on the board
/CM5_HighSpeed/PCIE_RX_N: Module1.118 (PCIe_RX_N); also elsewhere on the board
/CM5_HighSpeed/PCIE_RX_P: Module1.116 (PCIe_RX_P); also elsewhere on the board
/CM5_HighSpeed/PCIE_TX_N: Module1.124 (PCIe_TX_N); also elsewhere on the board
/CM5_HighSpeed/PCIE_TX_P: Module1.122 (PCIe_TX_P); also elsewhere on the board
/CM5_HighSpeed/PCIE_nCLKREQ: Module1.102 (PCIe_nCLKREQ); also elsewhere on the board
/CM5_HighSpeed/PCIE_nRST: Module1.109 (PCIe_nRST); also elsewhere on the board
/CM5_HighSpeed/PCIE_nWAKE: Module1.104 (PCIE_nWAKE); also elsewhere on the board
/CM5_HighSpeed/SCL0: J5.20; also elsewhere on the board
/CM5_HighSpeed/SDA0: J5.21; also elsewhere on the board
/CM5_HighSpeed/USB3-0-D_N: J12.A2 (D-), Module1.136 (USB3-0-D_N)
/CM5_HighSpeed/USB3-0-D_P: J12.A3 (D+), Module1.134 (USB3-0-D_P)
/CM5_HighSpeed/USB3-0-RX_N: J12.A6 (SSRX+), Module1.128 (USB3-0-RX_N)
/CM5_HighSpeed/USB3-0-RX_P: J12.A5 (SSRX-), Module1.130 (USB3-0-RX_P)
/CM5_HighSpeed/USB3-0-TX_N: J12.A9 (SSTX+), Module1.140 (USB3-0-TX_N)
/CM5_HighSpeed/USB3-0-TX_P: J12.A8 (SSTX-), Module1.142 (USB3-0-TX_P)
/CM5_HighSpeed/USB3-1-D_N: J12.B2 (D-), Module1.165 (USB3-1-D_N)
/CM5_HighSpeed/USB3-1-D_P: J12.B3 (D+), Module1.163 (USB3-1-D_P)
/CM5_HighSpeed/USB3-1-RX_N: J12.B6 (SSRX+), Module1.157 (USB3-1-RX_N)
/CM5_HighSpeed/USB3-1-RX_P: J12.B5 (SSRX-), Module1.159 (USB3-1-RX_P)
/CM5_HighSpeed/USB3-1-TX_N: J12.B9 (SSTX+), Module1.169 (USB3-1-TX_N)
/CM5_HighSpeed/USB3-1-TX_P: J12.B8 (SSTX-), Module1.171 (USB3-1-TX_P)
/CM5_HighSpeed/VBUS: C3.1, C7.1, C8.1, J12.A1 (VBUS), J12.B1 (VBUS), U6.6 (OUT)
/CM5_HighSpeed/VBUS_EN: Module1.111 (VBUS_EN), U6.3 (EN)
/USB2_N: Module1.103 (USB2_N); also elsewhere on the board
/USB2_P: Module1.105 (USB2_P); also elsewhere on the board
GND: C2.2, C3.2, C7.2, C8.2, C12.2, C13.2, J5.1, J5.4, J5.7, J5.10, J5.13, J5.16, J5.19, J12.10 (SHIELD), J12.A4 (GND), J12.A7 (DRAIN), J12.B4 (GND), J12.B7 (DRAIN), J22.2 (D2S), J22.5 (D1S), J22.8 (D0S), J22.11 (CKS), J22.17 (GND), J22.SH1 (SH), J22.SH2 (SH), J22.SH3 (SH), J22.SH4 (SH), Module1.107 (GND), Module1.108 (GND), Module1.113 (GND), Module1.114 (GND), Module1.119 (GND), Module1.120 (GND), Module1.125 (GND), Module1.126 (GND), Module1.131 (GND), Module1.132 (GND), Module1.137 (GND), Module1.138 (GND), Module1.144 (GND), Module1.150 (GND), Module1.155 (GND), Module1.156 (GND), Module1.161 (GND), Module1.162 (GND), Module1.167 (GND), Module1.168 (GND), Module1.173 (GND), Module1.174 (GND), Module1.179 (GND), Module1.180 (GND), Module1.185 (GND), Module1.186 (GND), Module1.191 (GND), Module1.192 (GND), Module1.197 (GND), Module1.198 (GND), R12.2, U6.2 (GND), U12.3 (GND); also elsewhere on the board
unnamed: J15.A1 (GND), J15.A12 (GND), J15.B1 (GND), J15.B12 (GND)
unnamed: J15.A4 (VBUS), J15.A9 (VBUS), J15.B4 (VBUS), J15.B9 (VBUS)
unnamed: R12.1, U6.5 (ILIM)

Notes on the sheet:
USB 3 Pairs P/N swapped to help routing
Current Limit switch
DSI/CSI Connectors
Stacked USB connectors

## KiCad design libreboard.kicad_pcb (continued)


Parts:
C4, C6, C14, C15, C16, C17: 10u; C_0805_2012Metric; Part Description 10uF 10% 10V Ceramic Capacitor X7R 0805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
C10, C19: 100n; C_0402_1005Metric; Part Description 0.1uF 10% 16V Ceramic Capacitor X7R 040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
C11: 4.7nF; C_0402_1005Metric; Part Description 4.7nF capacitor 0402
D3: LED Green; LED_0603_1608Metric; Part Description Green 572nm LED Indication - Discrete 2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
J4: Bus_M.2_Socket_M; M.2 M Key socket; Part Description M.2 M Key connector
L1: 2.2uH; L_Bourns_SRP5030CC; Part Description Inductor, SMT, 2520, 2u2, IRMS=7A, ISAT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
M1: M.2 Screw; Part Description M.2 Screw
M2, M3, M4, M5: M.2 Solder Nut; Part Description Solder nut for M.2 slot
R14: 100K 1%; R_0402_1005Metric; Part Description Resistor 100K M1005 1% 63mW
R15: 10K 1%; R_0402_1005Metric; Part Description Resistor 10K M1005 1% 63mW
R16: 2.2K 1%; R_0402_1005Metric; Part Description Resistor 2.2K M1005 1% 63mW
R17: 1k; R_0402_1005Metric; Part Description Resistor 1K M1005 1% 63mW
TP1: TestPoint; TestPoint_Pad_2.0x2.0mm; Part Description Test point; not fitted
U7: ASEK-32.768KHZ-L-R-T; Crystal_SMD_3225-4Pin_3.2x2.5mm; Part Description 32KHz Xtal oscilator
U8: AP3441SHE-7B; DFN-8-1EP_2x2mm_P0.5mm_EP1.05x1.75mm; Part Description 3A DC-DC converter

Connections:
/+5v: C4.1, C6.1, C10.1, U8.3 (VIN); also elsewhere on the board
/CM5_HighSpeed/PCIE_CLK_N: J4.53 (REFCLKn); also elsewhere on the board
/CM5_HighSpeed/PCIE_CLK_P: J4.55 (REFCLKp); also elsewhere on the board
/CM5_HighSpeed/PCIE_PWR_EN: R14.1, U8.7 (EN); also elsewhere on the board
/CM5_HighSpeed/PCIE_RX_N: J4.43 (PETp0); also elsewhere on the board
/CM5_HighSpeed/PCIE_RX_P: J4.41 (PETn0); also elsewhere on the board
/CM5_HighSpeed/PCIE_TX_N: J4.49 (PERp0); also elsewhere on the board
/CM5_HighSpeed/PCIE_TX_P: J4.47 (PERn0); also elsewhere on the board
/CM5_HighSpeed/PCIE_nCLKREQ: J4.52 (~CLKREQ); also elsewhere on the board
/CM5_HighSpeed/PCIE_nRST: J4.50 (~PERST); also elsewhere on the board
/CM5_HighSpeed/PCIE_nWAKE: J4.54 (~PEWAKE); also elsewhere on the board
/PCIe-M2/FB: C11.2, R15.2, R16.1, U8.1 (FB)
/PCIe-M2/M2_3v3: C11.1, C14.1, C15.1, C16.1, C17.1, C19.1, D3.2 (A), J4.2 (3.3V), J4.4 (3.3V), J4.12 (3.3V), J4.14 (3.3V), J4.16 (3.3V), J4.18 (3.3V), J4.70 (3.3V), J4.72 (3.3V), J4.74 (3.3V), L1.2, R15.1, U7.1 (EN), U7.4 (VDD)
GND: C4.2, C6.2, C10.2, C14.2, C15.2, C16.2, C17.2, C19.2, J4.1 (GND), J4.3 (GND), J4.9 (GND), J4.15 (GND), J4.21 (GND), J4.27 (GND), J4.33 (GND), J4.39 (GND), J4.45 (GND), J4.51 (GND), J4.57 (GND), J4.71 (GND), J4.73 (GND), J4.75 (GND), J4.M1 (GND2230), J4.M2 (GND2242), J4.M3 (GND2260), J4.M4 (GND2280), J4.S1, J4.S2, R14.2, R16.2, U7.2 (GND), U8.4 (PGND), U8.8 (SGND), U8.9 (PAD); also elsewhere on the board
unnamed: D3.1 (K), R17.1, TP1.1
unnamed: J4.10 (DAS/~DSS/~LED1), R17.2
unnamed: J4.68 (SUSCLK), U7.3 (Out)
unnamed: L1.1, U8.6 (LX)

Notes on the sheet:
Activity LED

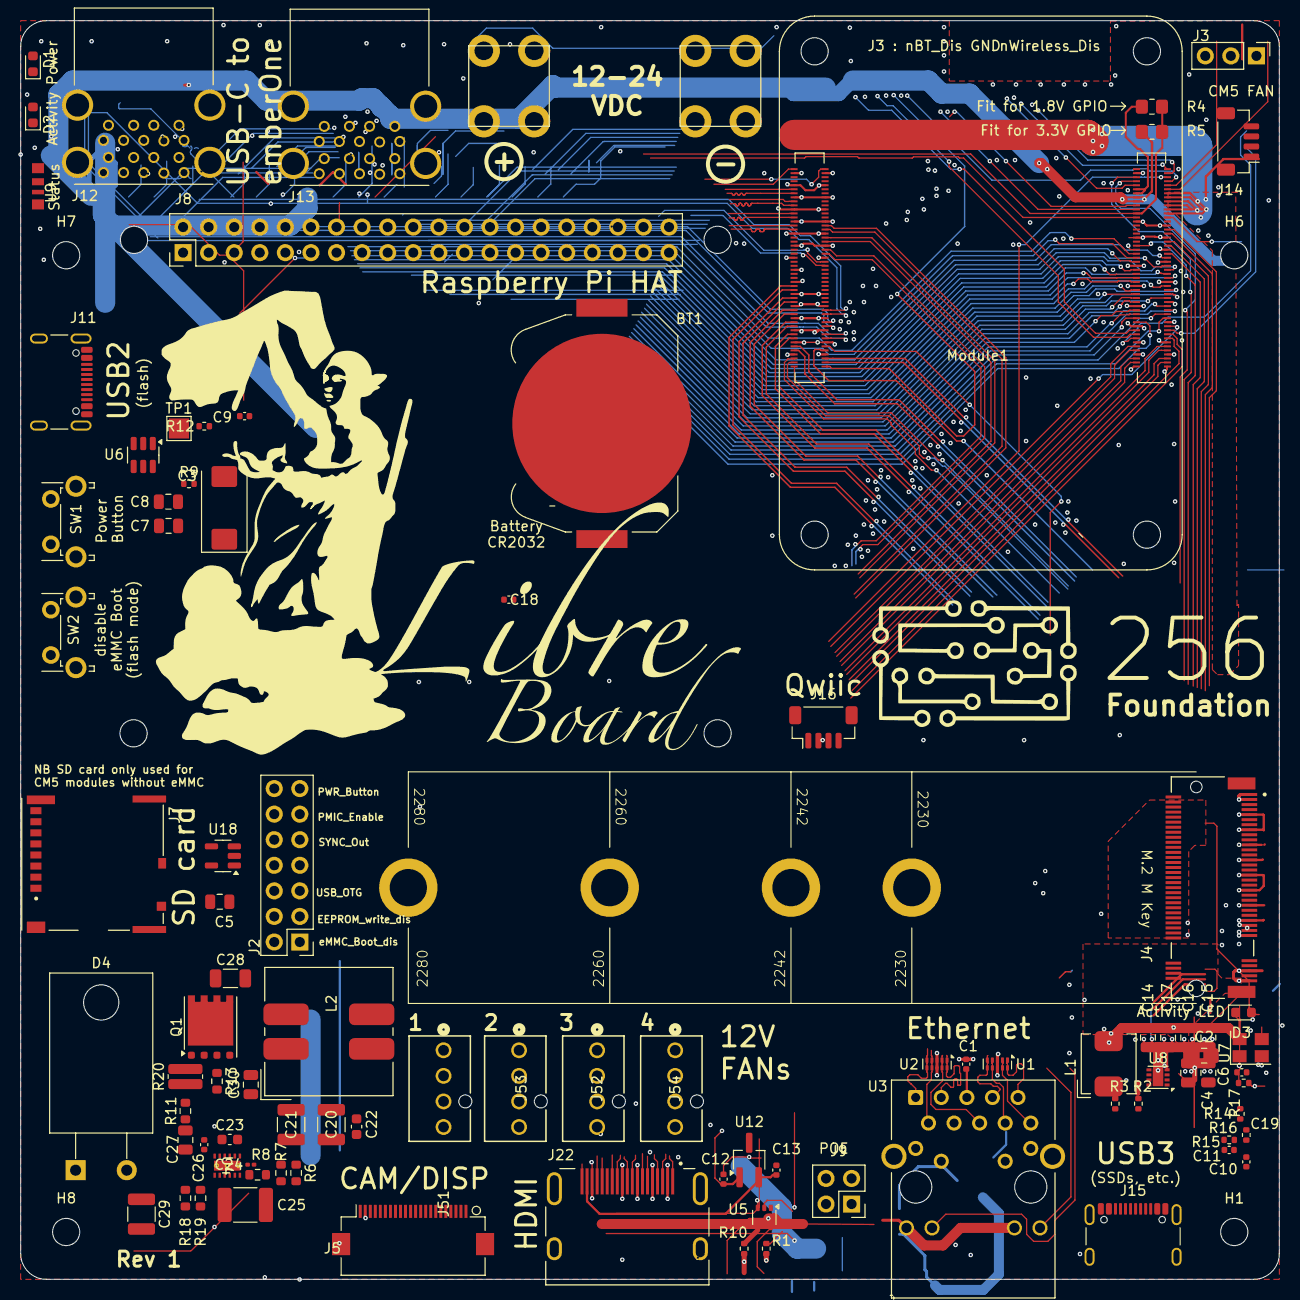
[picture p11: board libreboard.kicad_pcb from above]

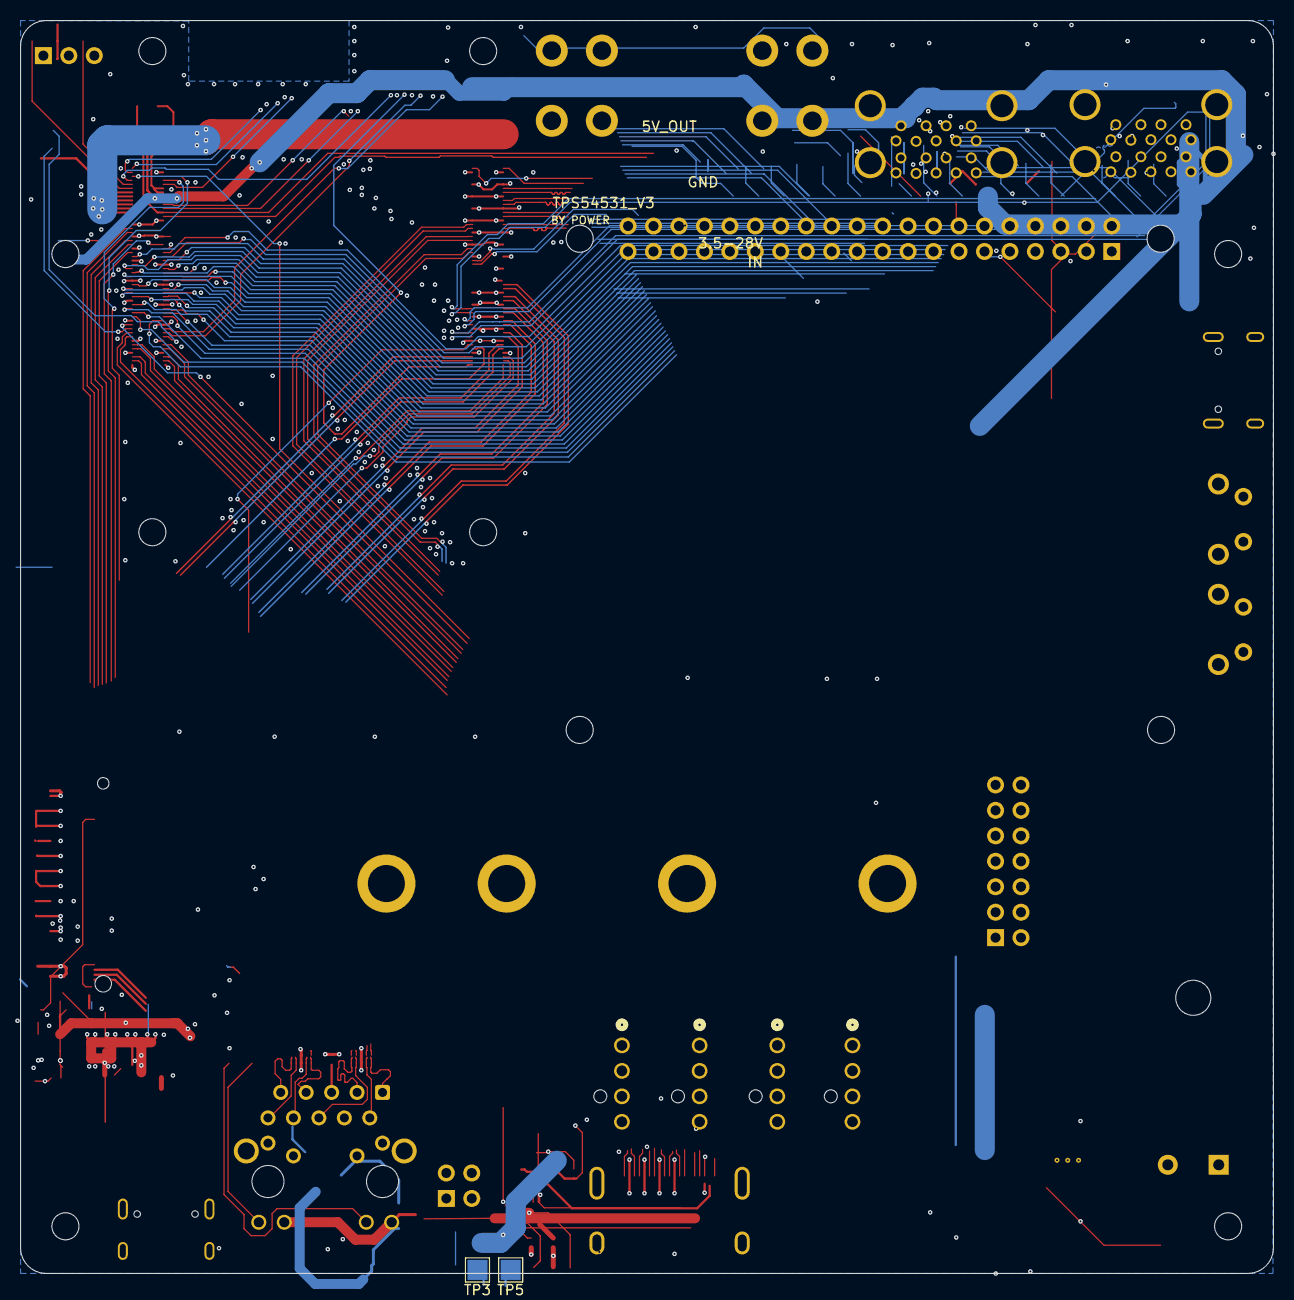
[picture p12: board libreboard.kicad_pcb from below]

Board: 4 copper layers, 125.0 x 125.0 mm, 103 parts (2 on the bottom side), 152 nets.

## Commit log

2025-05-05 Update README.md to include additional information and images for Libre-Board
2025-06-09 first commit of kicad
    [CM5_GPIO.kicad_sch, CM5_HighSpeed.kicad_sch, PCIe-M2.kicad_sch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]
2025-06-09 better 3d image which is not blue
    [libreboard.kicad_pcb]
2025-06-09 add qwicc
    [CM5_GPIO.kicad_sch, libreboard.kicad_pcb]

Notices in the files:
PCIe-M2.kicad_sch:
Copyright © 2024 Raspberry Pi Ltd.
